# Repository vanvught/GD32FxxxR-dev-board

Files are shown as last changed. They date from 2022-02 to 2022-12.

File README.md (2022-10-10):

[PayPal.Me Donate](https://paypal.me/AvanVught?locale.x=nl_NL)

-----------

# GD32F103R GD32F107R GD32F207R GD32F303R GD32F407R development board

This board can be used with the `GD32F103Rx`,  `GD32F303Rx` and the `GD32F107Rx` , `GD32F207Rx`, `GD32F407Rx` (Ethernet) MCU's. 

Please note that the crystal for the `GD32F107Rx`, `GD32F207Rx` and the `GD32F407Rx` is `25MHz` and the crystal for the `GD32F103Rx` and the  `GD32F303Rx` is `8MHz`.

The 2x13 header is pin compatible with the Orange Pi Zero and Raspberry Pi boards. 

Details -> [https://www.gd32-dmx.org/dev-board.html](https://www.gd32-dmx.org/dev-board.html)

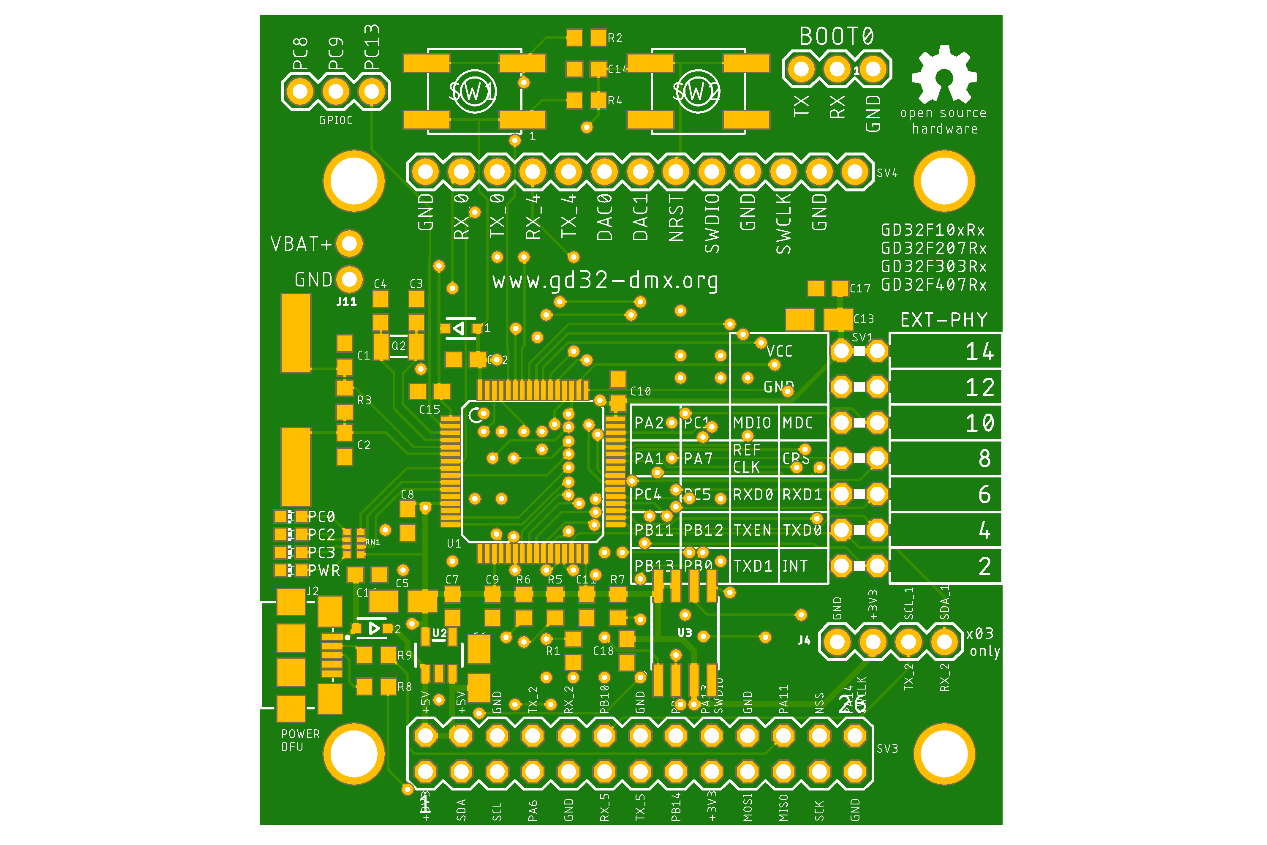
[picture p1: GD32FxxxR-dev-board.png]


# Add-on
Pixel 8x 4 Universes for the `GD32F207RG` / `GD32F407RE` 
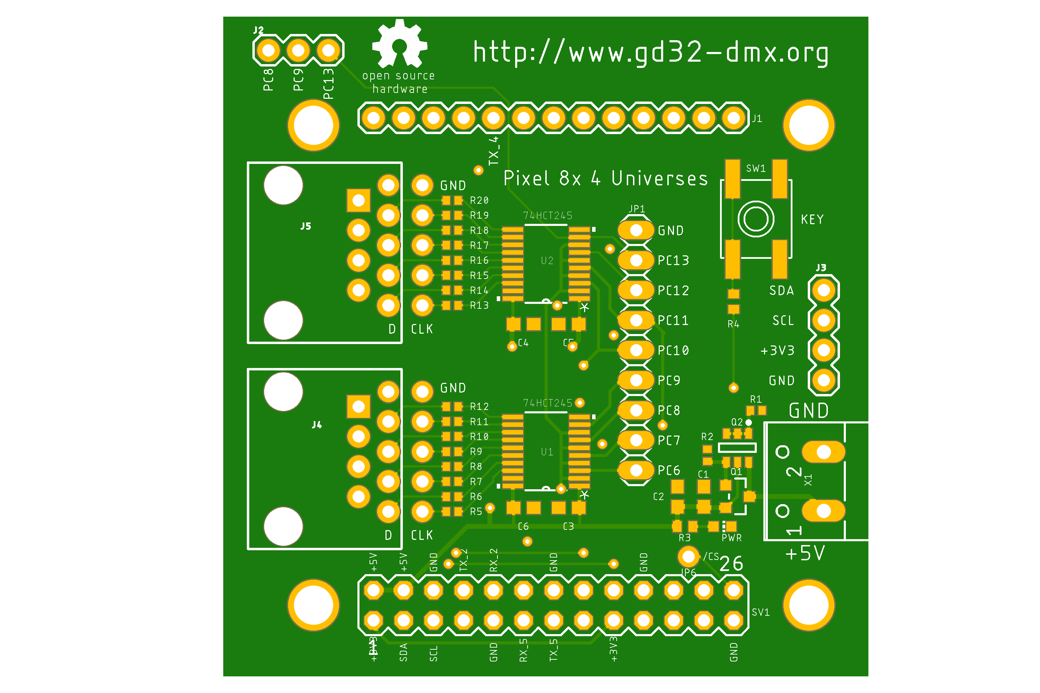
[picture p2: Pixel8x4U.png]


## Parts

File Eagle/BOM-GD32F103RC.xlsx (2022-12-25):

Qty | Designator | Footprint | Comment | LCSC Part #
2 | C1, C2 | C0603 | 20pF | C1648
2 | C3, C4 | C0603 | 12pF | C38523
3 | C5, C6, C13 | A/3216-18R | 10uF | C7171
11 | C7, C8, C9, C10, C11, C12, C14, C15, C16, C17, C18 | C0603 | 100n | C14663
4 | LED1, LED2, LED3, LED4 | CHIP-LED0603 | LEDCHIP-LED0603 | C72043
2 | D1, D2 | SOD323-R | 1N5819 | C191023
3 | R1, R2, R4 | R0603 | 10K | C25804
1 | R3 | R0603 | 1M | C22935
2 | R5,R6 | R0603 | 4K7 | C116693
1 | R7 | R0603 | 1K5 | C4190
2 | R8, R9 | R0603 | 22R | C23345
1 | RN1 | 4X0402ARV341 | 2K | C44891
1 | U1 | LQFP64 | GD32F103RC | C80687
1 | U2 | SOT23-5 | TPRT9013-33GB | C587158
1 | U3 | SOIC-8_208mil | W25Q128 | C97521
1 | J2 | 10118192-0002LF | USB-B-MICRO-SMD | C2972784
1 | Q1 | HC-49S-SMD-2P | 8 Mhz Crystal 20pF | C12674
1 | Q2 | FC-12M | 32.768kHz Crystal 12.5pF | C32346
2 | SW1, SW2 | EVQ-Q2 | SPST 6*6mm Tactile Switch | C221880
42

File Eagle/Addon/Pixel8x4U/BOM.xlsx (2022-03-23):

Qty | Designator | Footprint | Comment | LCSC Part #
4 | C1, C2, C3, C4 | C0603 | 100n | C14663
1 | LED1 | CHIP-LED0603 | PWR | C72043
1 | Q1 | SOT-23-3 | DMG2305UX | C144153
1 | Q2 | SOT-23-6L | DMMT5401-7-F_0_0 | C154733
1 | R1 | R0402 | 10K | C25744
1 | R2 | R0402 | 47K | C25792
1 | R3 | R0402 | 1K | C11702
8 | R4, R5, R6, R7, R8, R9, R10, R11 | R0402 | 100 | C25076
1 | U1 | SSOP-20 | 74HCT245 | C10910
19

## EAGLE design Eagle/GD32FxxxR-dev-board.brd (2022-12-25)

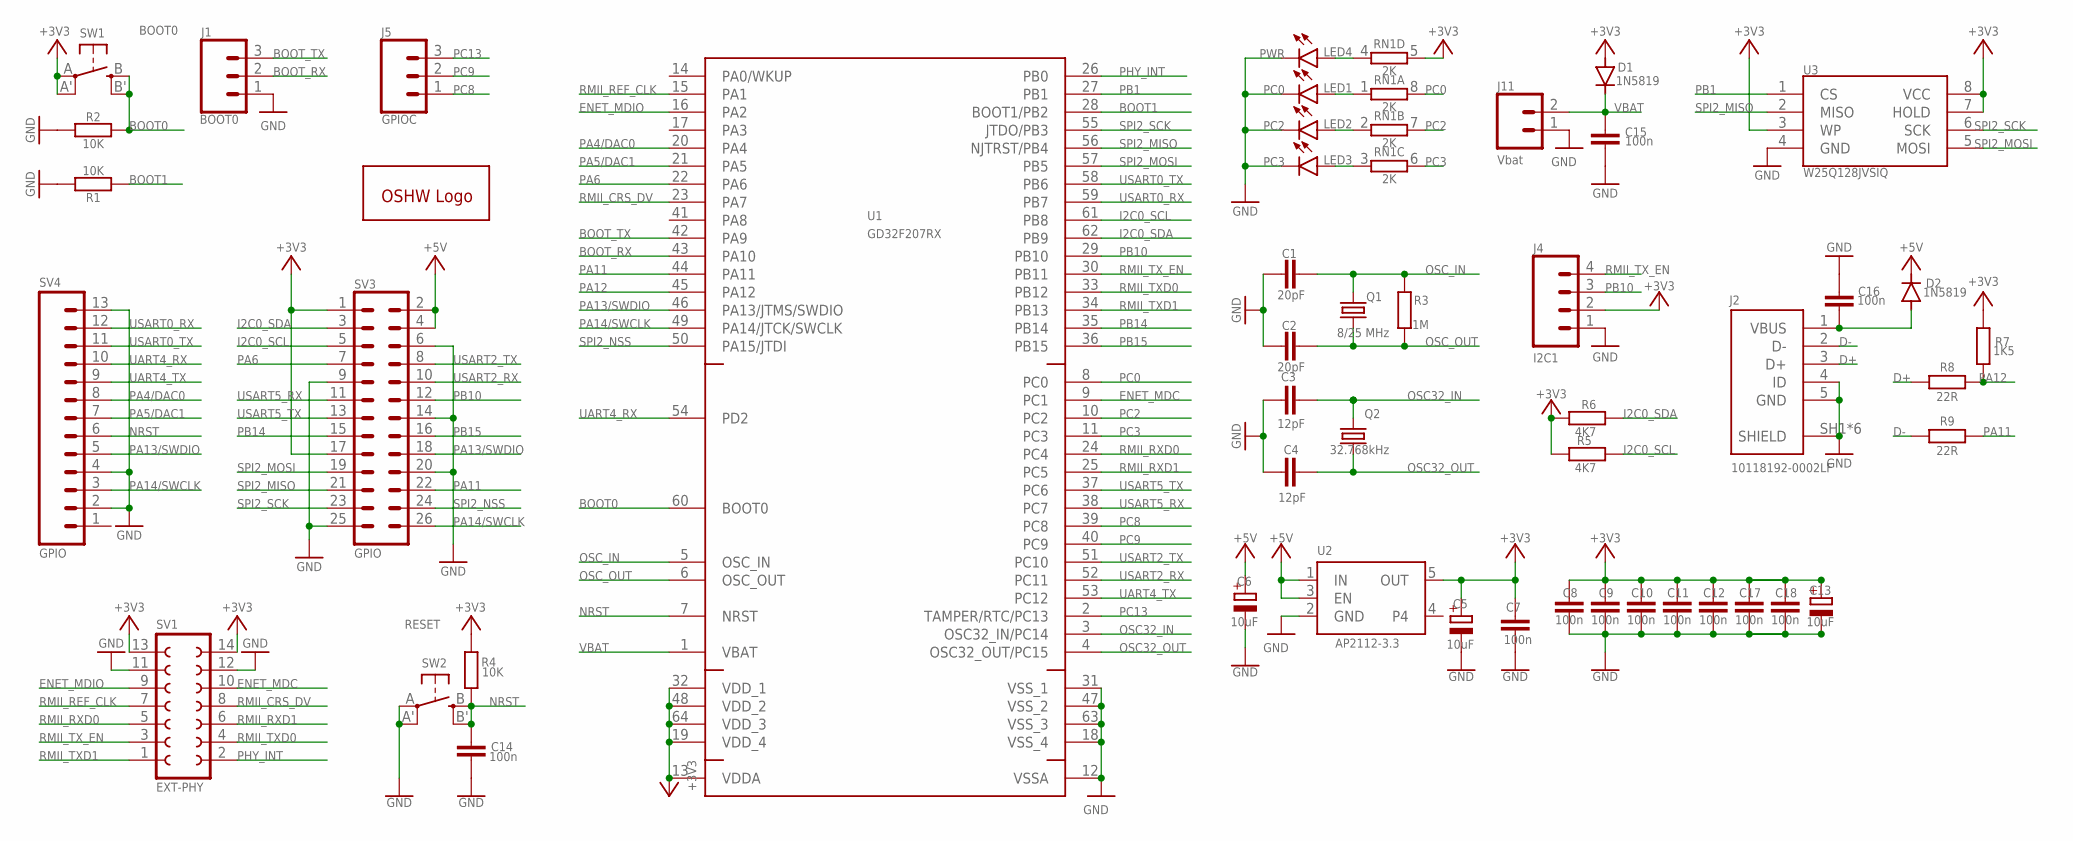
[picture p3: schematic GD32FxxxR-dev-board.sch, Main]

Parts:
C1, C2: 20pF; C0603; JLCPCB C38523
C3, C4: 12pF; C0603; JLCPCB C38523
C5, C6, C13: 10uF; A/3216-18R; JLCPCB C7171
C7, C8, C9, C10, C11, C12, C14, C15, C16, C17, C18: 100n; C0603; JLCPCB C14663
D1, D2: 1N5819; SOD323-R; JLCPCB C191023
GOLD_ORB_SM1: OSHWLOGOLOGO5MM; OSHW_5MM
J1: BOOT0; 1X03
J2: 10118192-0002LF; JLCPCB C2972784
J4: I2C1; 1X04
J5: GPIOC; 1X03
J11: Vbat; 1X02_NO_SILK
LED1: PC0; CHIP-LED0603
LED2: PC2; CHIP-LED0603
LED3: PC3; CHIP-LED0603
LED4: PWR; CHIP-LED0603
Q1: 8/25 MHz; CSM-7X-DU
Q2: 32.768kHz; 3.2X1.5; JLCPCB 32.768kHz
R1, R2, R4: 10K; R0603; JLCPCB C25804
R3: 1M; R0603; JLCPCB C22935
R5, R6: 4K7; R0603; JLCPCB C23162
R7: 1K5; R0603; JLCPCB C4190
R8, R9: 22R; R0603; JLCPCB C23345
RN1: 2K; 4X0402ARV341; JLCPCB C44891
SV1: EXT-PHY; FE07-2W
SV3: GPIO; MA13-2
SV4: GPIO; 1X13
SW1: BOOT0; EVQ-Q2; JLCPCB C221880
SW2: RESET; EVQ-Q2
U1: GD32F207RX; LQFP64
U2: AP2112-3.3; SOT23-5; JLCPCB C51118
U3: W25Q128JVSIQ; SO08-EIAJ; JLCPCB C97521

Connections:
+3V3: C5.+, C7.1, C8.1, C9.1, C10.1, C11.1, C12.1, C13.+, C17.1, C18.1, D1.A, J4.2, R4.2, R5.2, R6.2, R7.2, RN1.5 (2), SV1.13, SV1.14, SV3.1, SV3.17, SW1.A, SW1.A' (P1), U1.13 (VDDA), U1.19 (VDD_4), U1.32 (VDD_1), U1.48 (VDD_2), U1.64 (VDD_3), U2.5 (OUT), U3.3 (WP), U3.7 (HOLD), U3.8 (VCC)
+5V: C6.+, D2.C, SV3.2, SV3.4, U2.1 (IN), U2.3 (EN)
BOOT0: R2.2, SW1.B (S), SW1.B' (S1), U1.60 (BOOT0)
BOOT1: R1.1, U1.28 (BOOT1/PB2)
BOOT_RX: J1.2, U1.43 (PA10)
BOOT_TX: J1.3, U1.42 (PA9)
D+: J2.3 (D+), R8.1
D-: J2.2 (D-), R9.1
ENET_MDC: SV1.10, U1.9 (PC1)
ENET_MDIO: SV1.9, U1.16 (PA2)
GND: C1.1, C2.1, C3.1, C4.1, C5.-, C6.-, C7.2, C8.2, C9.2, C10.2, C11.2, C12.2, C13.-, C14.2, C15.2, C16.1, C17.2, C18.2, J1.1, J2.4 (ID), J2.5 (GND), J2.SH1 (SHIELD), J2.SH2 (SHIELD), J2.SH3 (SHIELD), J2.SH4 (SHIELD), J2.SH5 (SHIELD), J2.SH6 (SHIELD), J4.1, J11.1, LED1.C, LED2.C, LED3.C, LED4.C, R1.2, R2.1, SV1.11, SV1.12, SV3.6, SV3.9, SV3.14, SV3.20, SV3.25, SV4.2, SV4.4, SV4.13, SW2.A, SW2.A' (P1), U1.12 (VSSA), U1.18 (VSS_4), U1.31 (VSS_1), U1.47 (VSS_2), U1.63 (VSS_3), U2.2 (GND), U3.4 (GND)
I2C0_SCL: R5.1, SV3.5, U1.61 (PB8)
I2C0_SDA: R6.1, SV3.3, U1.62 (PB9)
unnamed: LED1.A, RN1.1
unnamed: LED2.A, RN1.2 (1)
unnamed: LED3.A, RN1.3 (1)
unnamed: LED4.A, RN1.4 (1)
NRST: C14.1, R4.1, SV4.6, SW2.B (S), SW2.B' (S1), U1.7 (NRST)
OSC32_IN: C3.2, Q2.2, U1.3 (OSC32_IN/PC14)
OSC32_OUT: C4.2, Q2.1, U1.4 (OSC32_OUT/PC15)
OSC_IN: C1.2, Q1.2, R3.1, U1.5 (OSC_IN)
OSC_OUT: C2.2, Q1.1, R3.2, U1.6 (OSC_OUT)
PA4/DAC0: SV4.8, U1.20 (PA4)
PA5/DAC1: SV4.7, U1.21 (PA5)
PA6: SV3.7, U1.22 (PA6)
PA11: R9.2, SV3.22, U1.44 (PA11)
PA12: R7.1, R8.2, U1.45 (PA12)
PA13/SWDIO: SV3.18, SV4.5, U1.46 (PA13/JTMS/SWDIO)
PA14/SWCLK: SV3.26, SV4.3, U1.49 (PA14/JTCK/SWCLK)
PB1: U1.27 (PB1), U3.1 (CS)
PB10: J4.3, SV3.12, U1.29 (PB10)
PB14: SV3.15, U1.35 (PB14)
PB15: SV3.16, U1.36 (PB15)
PC0: RN1.8 (2), U1.8 (PC0)
PC2: RN1.7 (2), U1.10 (PC2)
PC3: RN1.6 (2), U1.11 (PC3)
PC8: J5.1, U1.39 (PC8)
PC9: J5.2, U1.40 (PC9)
PC13: J5.3, U1.2 (TAMPER/RTC/PC13)
PHY_INT: SV1.2, U1.26 (PB0)
RMII_CRS_DV: SV1.8, U1.23 (PA7)
RMII_REF_CLK: SV1.7, U1.15 (PA1)
RMII_RXD0: SV1.5, U1.24 (PC4)
RMII_RXD1: SV1.6, U1.25 (PC5)
RMII_TXD0: SV1.4, U1.33 (PB12)
RMII_TXD1: SV1.1, U1.34 (PB13)
RMII_TX_EN: J4.4, SV1.3, U1.30 (PB11)
SPI2_MISO: SV3.21, U1.56 (NJTRST/PB4), U3.2 (MISO)
SPI2_MOSI: SV3.19, U1.57 (PB5), U3.5 (MOSI)
SPI2_NSS: SV3.24, U1.50 (PA15/JTDI)
SPI2_SCK: SV3.23, U1.55 (JTDO/PB3), U3.6 (SCK)
UART4_RX: SV4.10, U1.54 (PD2)
UART4_TX: SV4.9, U1.53 (PC12)
USART0_RX: SV4.12, U1.59 (PB7)
USART0_TX: SV4.11, U1.58 (PB6)
USART2_RX: SV3.10, U1.52 (PC11)
USART2_TX: SV3.8, U1.51 (PC10)
USART5_RX: SV3.11, U1.38 (PC7)
USART5_TX: SV3.13, U1.37 (PC6)
VBAT: C15.1, D1.C, J11.2, U1.1 (VBAT)
VBUS: C16.2, D2.A, J2.1 (VBUS)

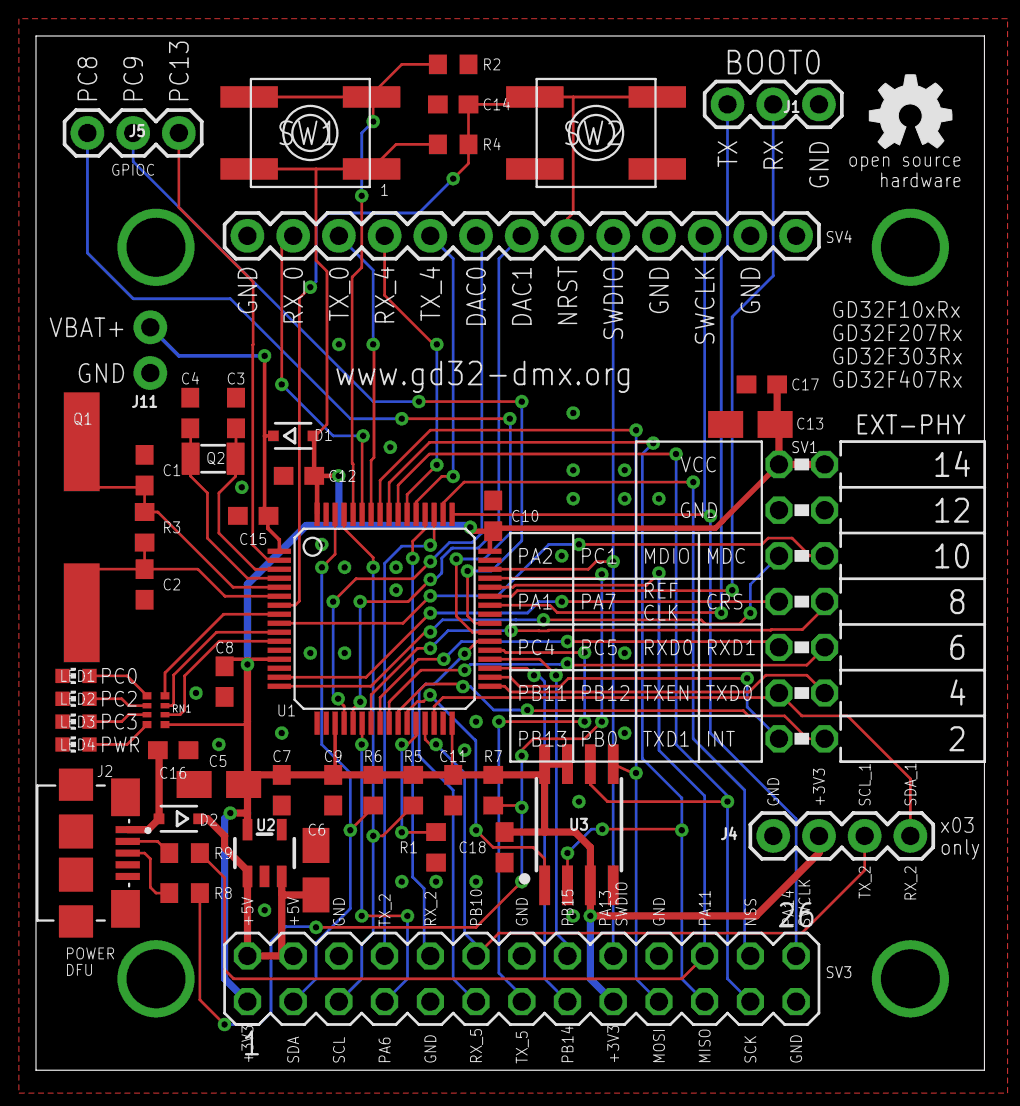
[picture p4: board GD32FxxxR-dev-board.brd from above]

Board: 2 copper layers, 52.7 x 57.5 mm, 50 parts (0 on the bottom side), 61 nets.

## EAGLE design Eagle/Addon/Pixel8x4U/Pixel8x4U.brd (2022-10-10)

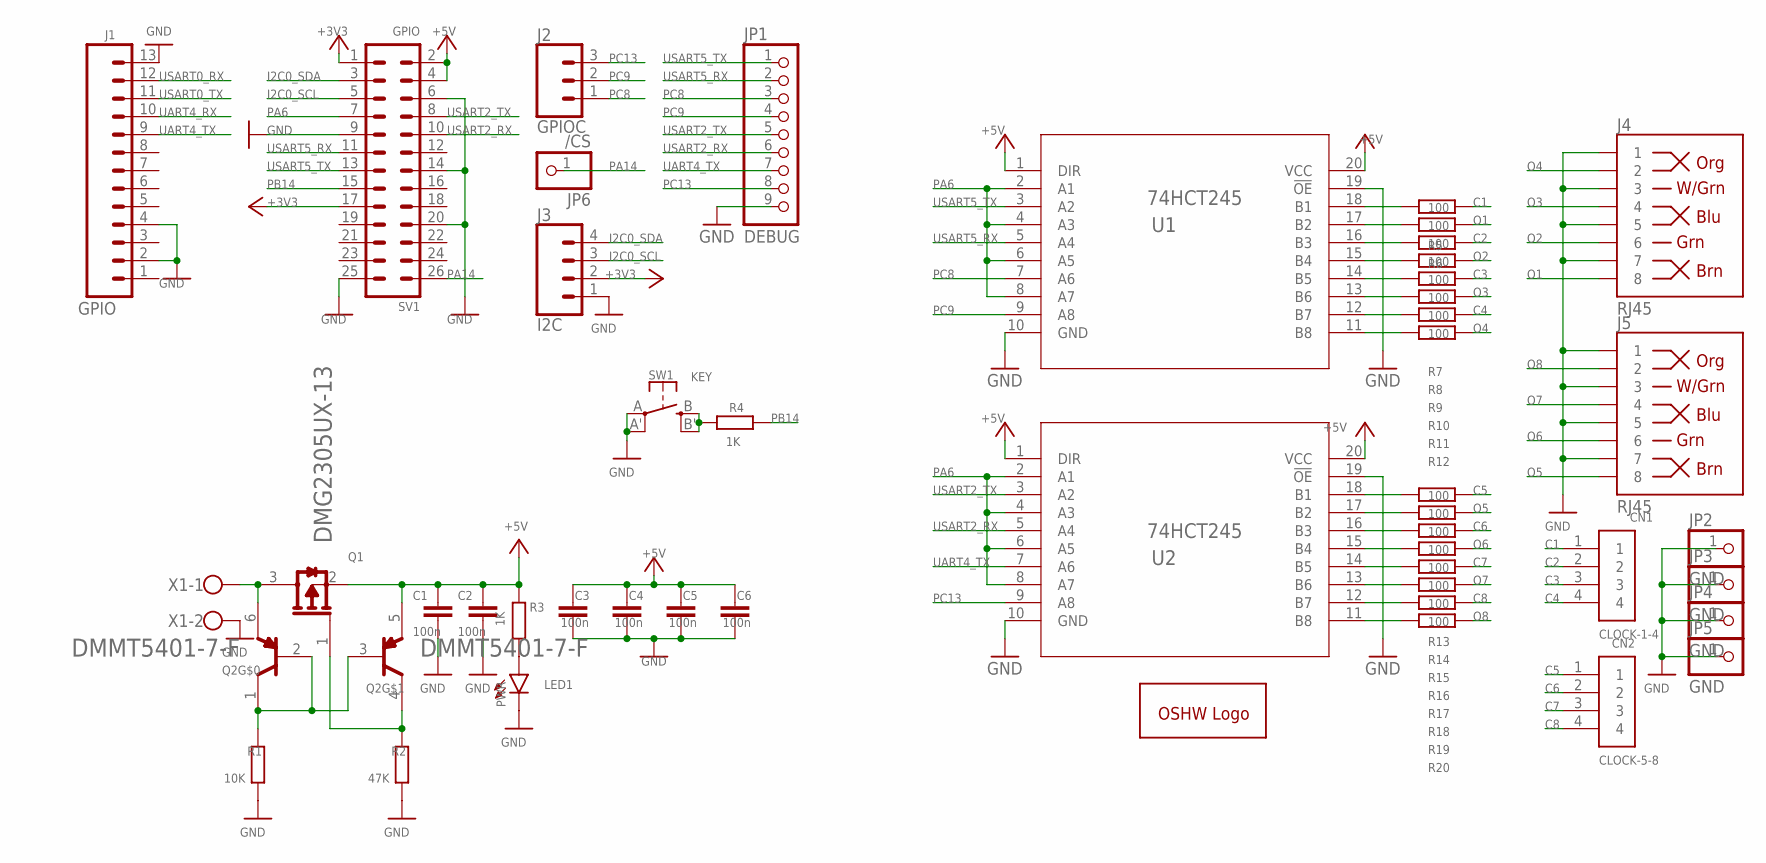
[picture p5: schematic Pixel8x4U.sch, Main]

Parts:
C1, C2, C3, C4, C5, C6: 100n; C0603
CN1: CLOCK-1-4; 1X04-CLEANBIG
CN2: CLOCK-5-8; 1X04-CLEANBIG
GOLD_ORB_SM1: OSHWLOGOLOGO5MM; OSHW_5MM
J1: GPIO; 1X13
J2: GPIOC; 1X03
J3: I2C; 1X04
J4, J5: RJ45; RJ45-8
JP1: DEBUG; 1X09
JP2, JP3, JP4, JP5: GND; 1X01-CLEANBIG
JP6: /CS; 1X01-CLEANBIG
LED1: PWR; CHIP-LED0603
Q1: DIODES_INC._DMG2305UX-13DIODES_INC._DMG2305UX-13_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; DIODES_INC._DMG2305UX-13_0
Q2: DMMT5401-7-F_0_0; DIODES_DMMT5401-7-F_0
R1: 10K; R0402
R2: 47K; R0402
R3, R4: 1K; R0402
R5, R6, R7, R8, R9, R10, R11, R12, R13, R14, R15, R16, R17, R18, R19, R20: 100; R0402
SV1: GPIO; MA13-2
SW1: KEY; EVQ-Q2
U1, U2: 74HCT245; PW20
X1: W237-102

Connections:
+3V3: J3.2, SV1.1, SV1.17
+5V: C1.1, C2.1, C3.1, C4.1, C5.1, C6.1, Q1.2 (S), Q2.5 (E2), R3.1, SV1.2, SV1.4, U1.1 (DIR), U1.20 (VCC), U2.1 (DIR), U2.20 (VCC)
C1: CN1.1, R5.2
C2: CN1.2, R7.2
C3: CN1.3, R9.2
C4: CN1.4, R11.2
C5: CN2.1, R13.2
C6: CN2.2, R15.2
C7: CN2.3, R17.2
C8: CN2.4, R19.2
GND: C1.2, C2.2, C3.2, C4.2, C5.2, C6.2, J1.2, J1.4, J1.13, J3.1, J4.1, J4.3, J4.5, J4.7, J5.1, J5.3, J5.5, J5.7, JP1.9, JP2.1, JP3.1, JP4.1, JP5.1, LED1.C, R1.1, R2.1, SV1.6, SV1.9, SV1.14, SV1.20, SV1.25, SW1.A, SW1.A' (P1), U1.10 (GND), U1.19 (!OE), U2.10 (GND), U2.19 (!OE), X1.2
I2C0_SCL: J3.3, SV1.5
I2C0_SDA: J3.4, SV1.3
unnamed: Q2.1 (C1), Q2.2 (B1), Q2.3 (B2), R1.2
unnamed: Q1.3 (D), Q2.6 (E1), X1.1
unnamed: Q1.1 (G), Q2.4 (C2), R2.2
unnamed: R4.1, SW1.B (S), SW1.B' (S1)
unnamed: R6.1, U1.17 (B2)
unnamed: R12.1, U1.11 (B8)
unnamed: R10.1, U1.13 (B6)
unnamed: R8.1, U1.15 (B4)
unnamed: R5.1, U1.18 (B1)
unnamed: R7.1, U1.16 (B3)
unnamed: R14.1, U2.17 (B2)
unnamed: R16.1, U2.15 (B4)
unnamed: R18.1, U2.13 (B6)
unnamed: LED1.A, R3.2
unnamed: R20.1, U2.11 (B8)
unnamed: R9.1, U1.14 (B5)
unnamed: R11.1, U1.12 (B7)
unnamed: R13.1, U2.18 (B1)
unnamed: R15.1, U2.16 (B3)
unnamed: R17.1, U2.14 (B5)
unnamed: R19.1, U2.12 (B7)
O1: J4.8, R6.2
O2: J4.6, R8.2
O3: J4.4, R10.2
O4: J4.2, R12.2
O5: J5.8, R14.2
O6: J5.6, R16.2
O7: J5.4, R18.2
O8: J5.2, R20.2
PA6: SV1.7, U1.2 (A1), U1.4 (A3), U1.6 (A5), U1.8 (A7), U2.2 (A1), U2.4 (A3), U2.6 (A5), U2.8 (A7)
PA14: JP6.1, SV1.26
PB14: R4.2, SV1.15
PC8: J2.1, JP1.3, U1.7 (A6)
PC9: J2.2, JP1.4, U1.9 (A8)
PC13: J2.3, JP1.8, U2.9 (A8)
UART4_RX: J1.10
UART4_TX: J1.9, JP1.7, U2.7 (A6)
USART0_RX: J1.12
USART0_TX: J1.11
USART2_RX: JP1.6, SV1.10, U2.5 (A4)
USART2_TX: JP1.5, SV1.8, U2.3 (A2)
USART5_RX: JP1.2, SV1.11, U1.5 (A4)
USART5_TX: JP1.1, SV1.13, U1.3 (A2)

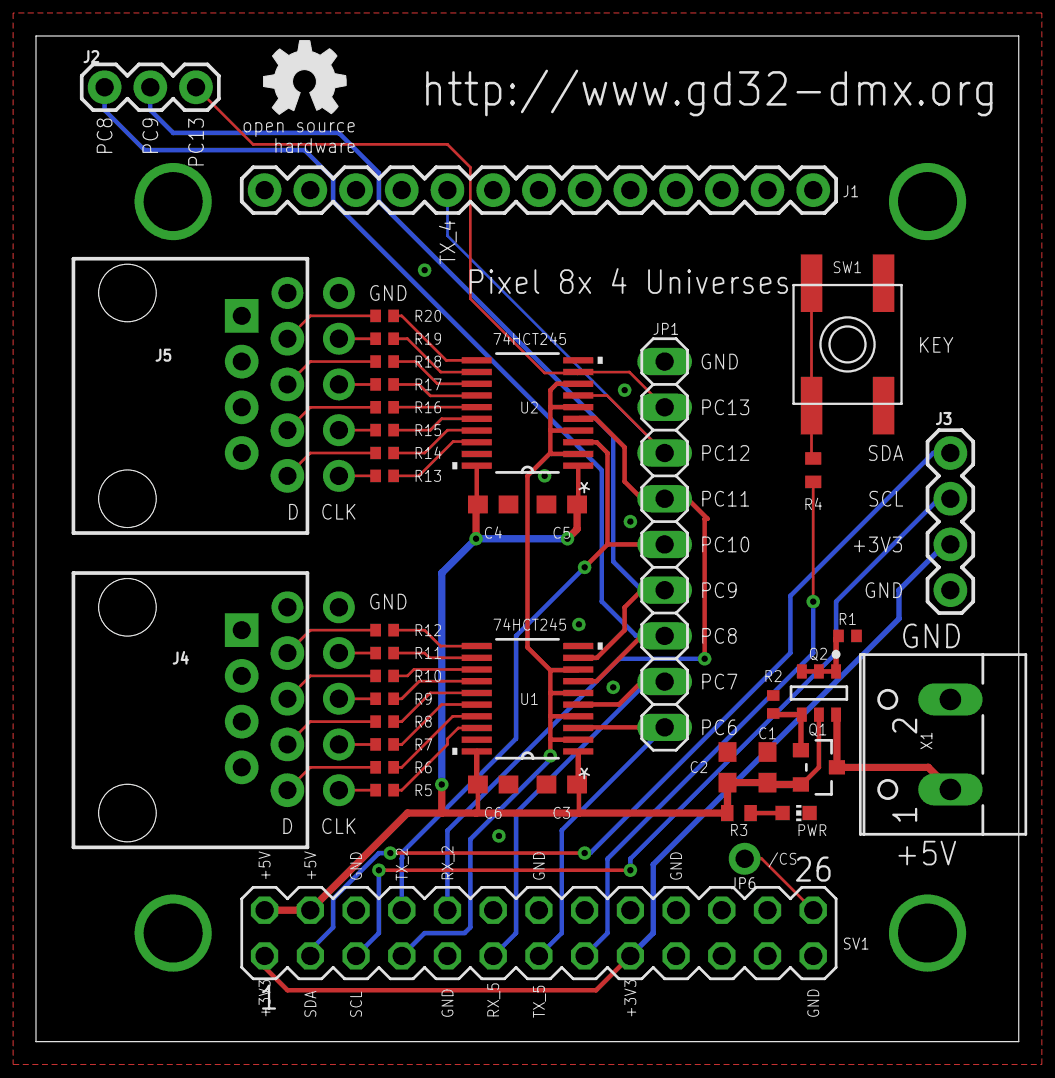
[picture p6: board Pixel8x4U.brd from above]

Board: 2 copper layers, 54.6 x 55.9 mm, 48 parts (0 on the bottom side), 53 nets.

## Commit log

2022-03-23 Added GD32F303R
    [BOM-GD32F103RC.xlsx, BOM-GD32F107RC.xlsx, BOM-GD32F303RC.xlsx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]
2022-10-10 Updated Add-on Pixel 8x 4 Universes
    *. Added support for clock based led chip's (for example APA102)
    [GD32FxxxR-dev-board.brd, GD32FxxxR-dev-board.sch, Pixel8x4U.brd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]
2022-12-25 Added SPI Flash ROM
    [BOM-GD32F103RC.xlsx, BOM-GD32F107RC.xlsx, BOM-GD32F207RG.xlsx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]

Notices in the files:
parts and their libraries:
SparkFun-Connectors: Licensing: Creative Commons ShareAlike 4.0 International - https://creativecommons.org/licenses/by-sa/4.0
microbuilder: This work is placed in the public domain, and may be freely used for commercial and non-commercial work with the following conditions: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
